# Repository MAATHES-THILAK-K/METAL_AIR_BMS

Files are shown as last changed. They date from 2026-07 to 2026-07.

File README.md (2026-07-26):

# 🔋 Metal-Air Single Cell Battery Management System 




<p align="center">
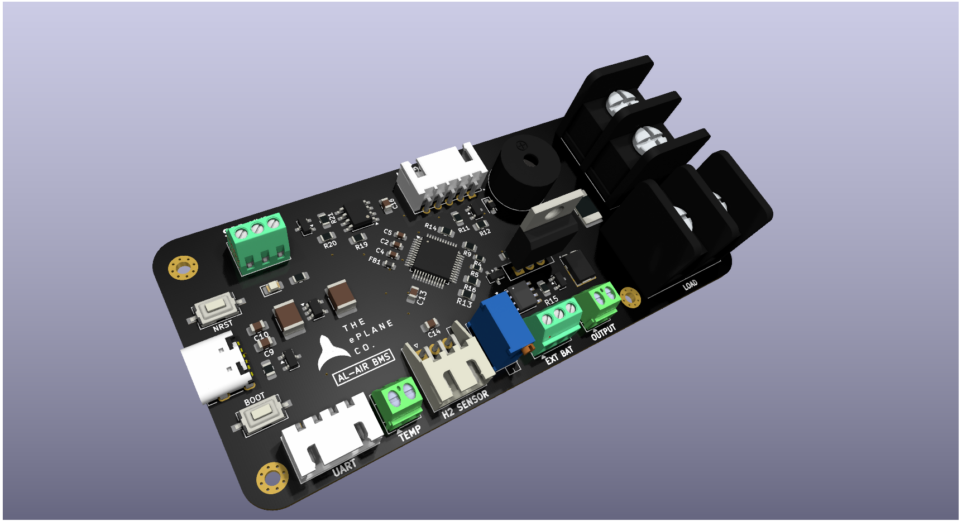
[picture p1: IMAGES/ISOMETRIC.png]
PCB Render
  
</p>

---

## 📖 Overview

The **Metal-Air Single Cell Battery Management System (BMS)** is a custom embedded system designed to safely monitor and protect a single-cell Metal-Air battery. The project is built around the **STM32G0B1CBT6** microcontroller and provides real-time monitoring of battery voltage, current, temperature, and hydrogen gas concentration while implementing multiple protection mechanisms to ensure reliable battery operation.

The repository contains the complete embedded firmware, hardware design files, Python monitoring application, and supporting documentation required to reproduce the project.

---

## ✨ Key Features

* STM32G0B1CBT6 Microcontroller
* INA226 High-Precision Current & Bus Voltage Monitoring
* NTC Thermistor-Based Temperature Measurement
* Hydrogen Gas Sensor Monitoring
* Real-Time Fault Detection
* Over-Current Protection (OCP)
* Under-Voltage Protection (UVP)
* Over-Temperature Protection (OTP)
* UART Communication
* Python-Based Monitoring & Data Logging
* Audible Fault Indication (Buzzer)
* MOSFET-Based Load Disconnect

---

## 🏗️ System Architecture

```text
                  +----------------------------+
                  |    Metal-Air Battery       |
                  +-------------+--------------+
                                |
                 +--------------v--------------+
                 |       STM32G0B1CBT6         |
                 +--------------+--------------+
                                |
     +------------+-------------+------------+--------------+
     |            |                          |              |
     |            |                          |              |
+----v----+ +-----v-----+            +-------v------+ +-----v------+
| INA226  | | NTC Sensor|            | H₂ Sensor    | | UART Debug |
| Current | |Temperature|            | Monitoring   | | / Logging  |
+---------+ +-----------+            +--------------+ +------------+
       |                                           |
       +----------------------+--------------------+
                              |
                      +-------v--------+
                      | Protection     |
                      | Decision Logic |
                      +-------+--------+
                              |
                   +----------v-----------+
                   | MOSFET Load Control  |
                   +----------------------+
```

---

## 🔧 Hardware

### Microcontroller

* STM32G0B1CBT6

### Sensors

* INA226 Current & Bus Voltage Sensor
* NTC Thermistor
* Hydrogen Gas Sensor

### Output Devices

* Protection MOSFET
* Buzzer

### Communication

* UART Serial Interface

---

## 💻 Firmware

The embedded firmware continuously performs the following tasks:

* Battery Voltage Measurement
* Current Measurement
* Temperature Monitoring
* Hydrogen Gas Detection
* Fault Monitoring
* Protection Decision Making
* MOSFET Control
* UART Data Transmission for Monitoring

---

## 📂 Project Structure

```text
Metal-Air-Single-Cell-BMS/
│
├── Firmware/
│   └── Metal_Air_BMS.ino
│
├── Python/
│   └── BMS_Monitor.py
│
├── Hardware/
│   ├── Schematic.pdf
│   ├── PCB.pdf
│   ├── PCB_Render.png
│   ├── PCB_Top.png
│   ├── PCB_Bottom.png
│   ├── Gerber.zip
│   ├── BOM.xlsx
│   └── Pick_and_Place.csv
│
├── Images/
│   ├── PCB_Render.png
│   ├── Completed_PCB.jpg
│   ├── Wiring_Diagram.png
│   └── Block_Diagram.png
│
├── README.md
├── requirements.txt
└── .gitignore
```

---

## 🚀 Getting Started

### Hardware

1. Assemble the PCB.
2. Connect the Metal-Air battery.
3. Connect the sensors.
4. Verify all wiring before powering the system.

### Firmware

Compile the firmware using the **Arduino IDE** with the **STM32 Arduino Core** installed.

Upload the firmware using:

* ST-Link
* UART Bootloader

---

## 🎯 Applications

* Metal-Air Battery Research
* Battery Safety Systems
* Embedded Systems Development
* Laboratory Testing
* Battery Performance Evaluation
* Educational and Research Projects

---

## 👨‍💻 Author

**MAATHES THILAK K**

Electronics and Communication Engineering

Anna University, MIT Campus, Chennai

---
⭐ If you found this project useful, consider giving it a **Star**!

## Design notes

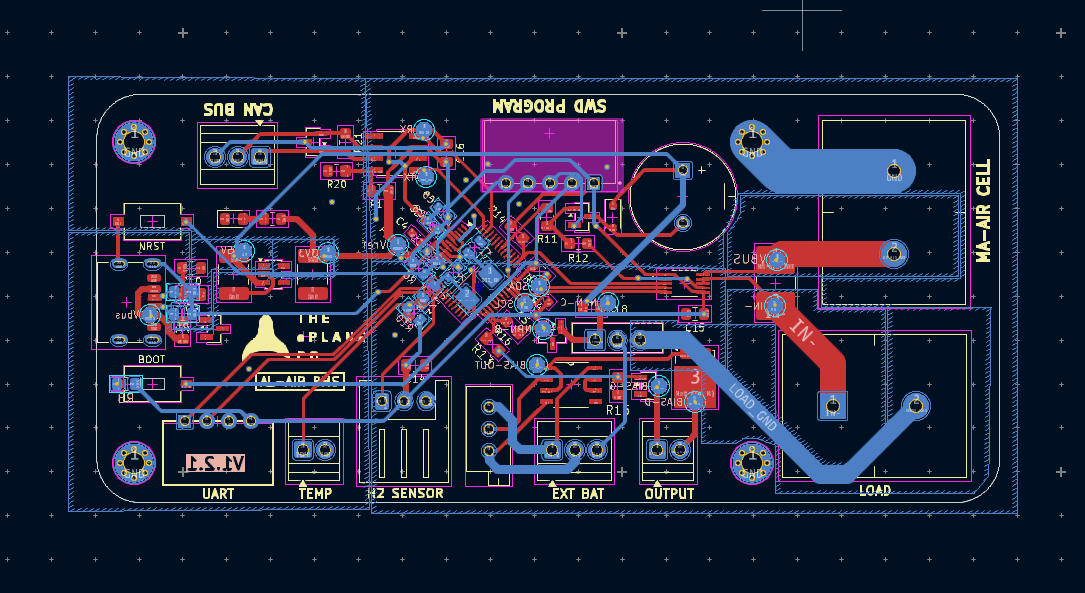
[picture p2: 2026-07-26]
IMAGES/Screenshot from 2026-06-24 11-21-53.png

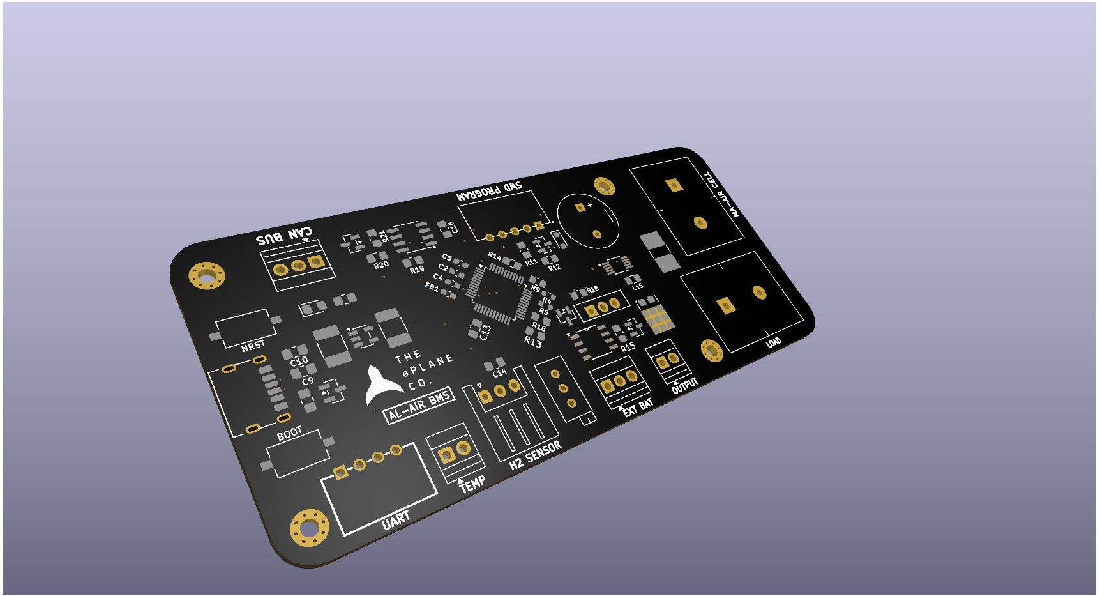
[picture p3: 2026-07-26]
IMAGES/ISOMETRIC_SMD.png

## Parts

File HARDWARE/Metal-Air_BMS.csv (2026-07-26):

Id | Designator | Footprint | Quantity | Designation | Supplier and ref
1 | F1 | Fuse_0805_2012Metric_Pad1.15x1.40mm_HandSolder | 1 | Fuse
2 | R12,R14,R20,R15,R18,R10 | R_0805_2012Metric_Pad1.20x1.40mm_HandSolder | 6 | 10k
3 | U4 | SOIC-8_3.9x4.9mm_P1.27mm | 1 | SN65HVD230
4 | TH1 | TerminalBlock_Xinya_XY308-2.54-2P_1x02_P2.54mm_Horizontal | 1 | 100k ,B=3950
5 | D4 | TO-277A | 1 | ST2045L
6 | C4 | C_0603_1608Metric | 1 | 1uF
7 | R5,R4 | R_0603_1608Metric | 2 | 4k7
8 | R13,R11 | R_0805_2012Metric_Pad1.20x1.40mm_HandSolder | 2 | 100
9 | Q3 | SOT-23 | 1 | BC547
10 | J5,J10 | TerminalBlock_Xinya_XY308-2.54-3P_1x03_P2.54mm_Horizontal | 2 | 01x03
11 | RV1 | Potentiometer_Bourns_3296X_Horizontal | 1 | 10k
12 | J6 | TerminalBlock_Xinya_XY845A-9.50-2P_1x02_P9.50mm | 1 | 01x02
13 | C3,C7 | C_1812_4532Metric_Pad1.57x3.40mm_HandSolder | 2 | 6.8uF
14 | MOSFET1 | TO-220-3_Vertical | 1 | IRLB8743PBF
15 | Q2,Q1 | SOT-23 | 2 | CMN2302M
16 | C2,C5,C1,C6 | C_0603_1608Metric | 4 | 100nF
17 | J1 | USB_C_Receptacle_HRO_TYPE-C-31-M-17 | 1 | USB 3.1 Type-C 6
18 | C9 | C_0805_2012Metric_Pad1.18x1.45mm_HandSolder | 1 | 10uF
19 | J8 | TerminalBlock_Xinya_XY845A-9.50-2P_1x02_P9.50mm | 1 | LOAD
20 | C16,C13,C15,C10,C14 | C_0805_2012Metric_Pad1.18x1.45mm_HandSolder | 5 | 100nF
21 | R3 | R_0805_2012Metric_Pad1.20x1.40mm_HandSolder | 1 | 1k
22 | R21 | R_0805_2012Metric_Pad1.20x1.40mm_HandSolder | 1 | 120
23 | SW1,SW2 | SW_Tactile_SPST_NO_Straight_CK_PTS636Sx25SMTRLFS | 2 | PUSH
24 | FB1 | L_0603_1608Metric | 1 | 220R @ 100MHz
25 | U3 | INA226 | 1 | INA226
26 | D5,D1 | SOT-23 | 2 | TVS_DUAL
27 | J9 | CONN-TH_4P-P2.50_WAFER-XH254WZ-4A | 1 | 01x04
28 | R17 | R_2816_7142Metric_Pad3.20x4.45mm_HandSolder | 1 | 3m
29 | U2 | LQFP-48_7x7mm_P0.5mm | 1 | STM32G0B1CBTx
30 | J7 | TerminalBlock_Xinya_XY308-2.54-2P_1x02_P2.54mm_Horizontal | 1 | 01x02
31 | R19 | R_0805_2012Metric_Pad1.20x1.40mm_HandSolder | 1 | 0
32 | U5 | TS9121IDT | 1 | TS912IDT
33 | D2 | LED_0805_2012Metric_Pad1.15x1.40mm_HandSolder | 1 | LED
34 | J4 | JST_XH_S3B-XH-A_1x03_P2.50mm_Horizontal | 1 | 01x03
35 | R9,R6 | R_0805_2012Metric | 2 | 10k
36 | U1 | SOT-23-5 | 1 | SSP7603P33M5R
37 | J3 | Buzzer_12x9.5RM6.0 | 1 | 01x02
38 | R16 | R_0805_2012Metric_Pad1.20x1.40mm_HandSolder | 1 | 4k7
39 | D3 | D_SOD-323_HandSoldering | 1 | RB550V
40 | J2 | JST_GENERIC_5-PIN | 1 | 01x05
41 | TP10 | TestPoint_Pad_D1.5mm | 1 | VBUS
42 | TP5 | TestPoint_Pad_D1.5mm | 1 | Vref
43 | C8 | C_0603_1608Metric | 1 | 4.7uF
44 | TP11 | TestPoint_Pad_D1.5mm | 1 | NPN-B
45 | TP8 | TestPoint_Pad_D1.5mm | 1 | RX
46 | R1,R2 | R_0805_2012Metric_Pad1.20x1.40mm_HandSolder | 2 | 5.1k
47 | R7 | R_0603_1608Metric | 1 | 620
48 | TP6 | TestPoint_Pad_D1.5mm | 1 | SCL
49 | TP4 | TestPoint_Pad_D1.5mm | 1 | SDA
50 | TP2 | TestPoint_Pad_D1.5mm | 1 | Vbus
51 | C12,C11 | C_0805_2012Metric | 2 | 30pF
52 | TP9 | TestPoint_Pad_D1.5mm | 1 | IN-
53 | Y1 | Crystal_SMD_5032-2Pin_5.0x3.2mm | 1 | 8MHz
54 | TP7 | TestPoint_Pad_D1.5mm | 1 | TX
55 | TP1 | TestPoint_Pad_D1.5mm | 1 | 5V
56 | R8 | R_0805_2012Metric_Pad1.20x1.40mm_HandSolder | 1 | 330
57 | TP16 | TestPoint_Pad_D1.5mm | 1 | BIAS-OUT
58 | TP13 | TestPoint_Pad_D1.5mm | 1 | NPN-C
59 | TP3 | TestPoint_Pad_D1.5mm | 1 | 3V3
60 | TP14 | TestPoint_Pad_D1.5mm | 1 | BIAS-D
61 | TP12 | TestPoint_Pad_D1.5mm | 1 | BIAS-G

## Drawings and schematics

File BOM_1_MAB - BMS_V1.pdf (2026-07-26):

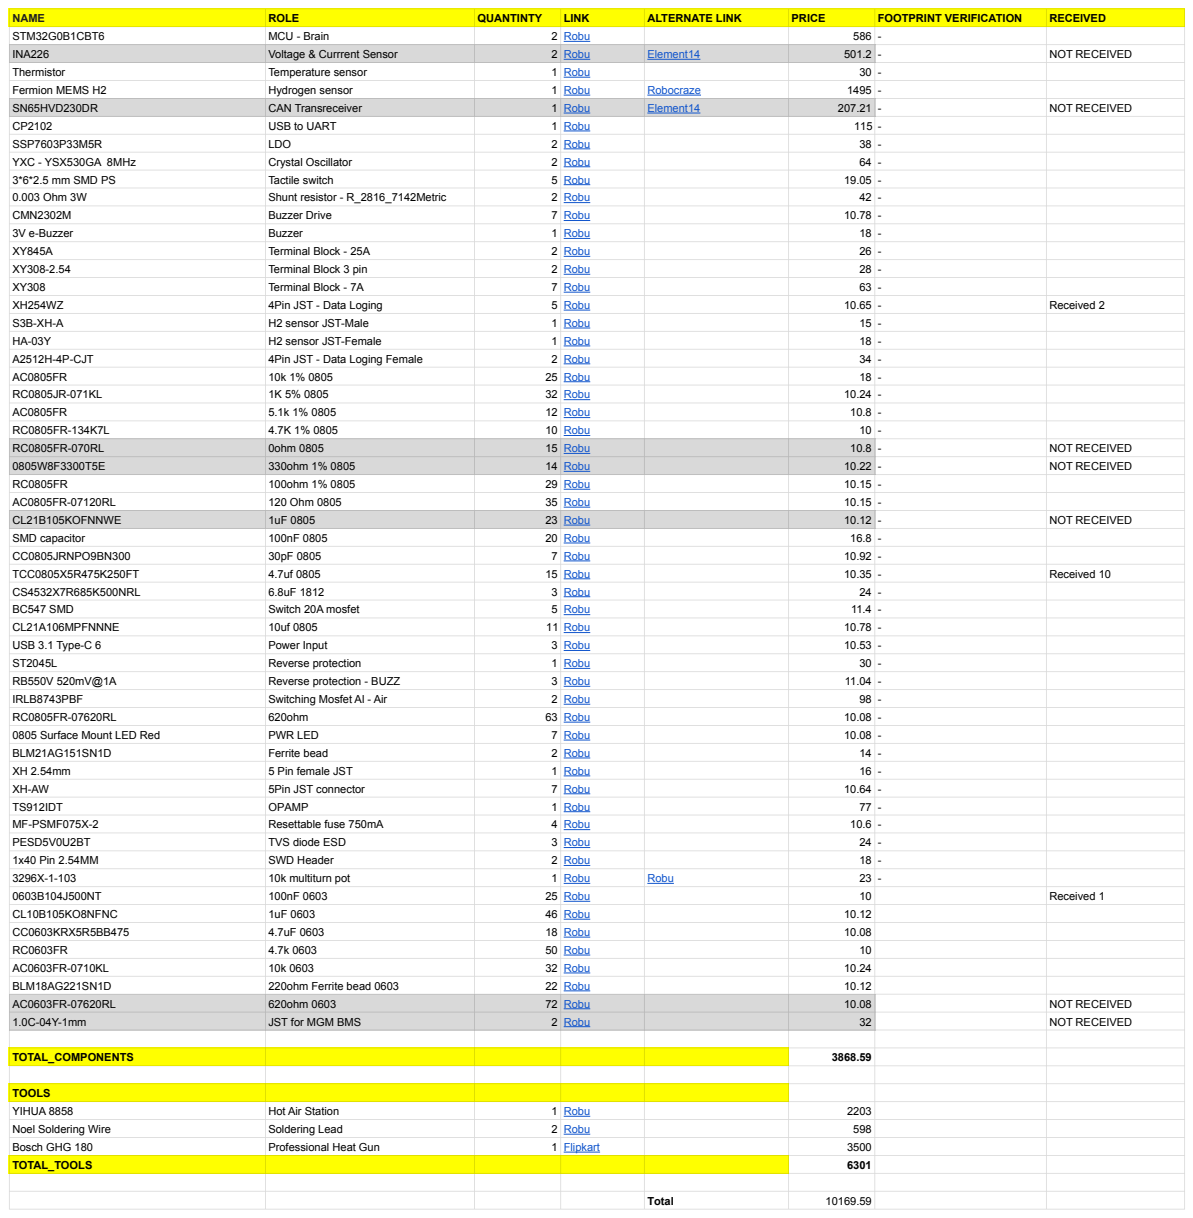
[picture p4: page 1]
NAME; ROLE; QUANTINTY; LINK; ALTERNATE LINK; PRICE; FOOTPRINT VERIFICATION; RECEIVED; STM32G0B1CBT6; MCU - Brain; 2 Robu; INA226; Voltage & Currrent Sensor; Element14; NOT RECEIVED; Thermistor; Temperature sensor; 1 Robu; Fermion MEMS H2; Hydrogen sensor; Robocraze; SN65HVD230DR; CAN Transreceiver; USB to UART; SSP7603P33M5R; LDO; YXC - YSX530GA 8MHz; Crystal Oscillator; 3*6*2.5 mm SMD PS; Tactile switch; 5 Robu; 0.003 Ohm 3W; Shunt resistor - R_2816_7142Metric; CMN2302M; Buzzer Drive; 7 Robu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

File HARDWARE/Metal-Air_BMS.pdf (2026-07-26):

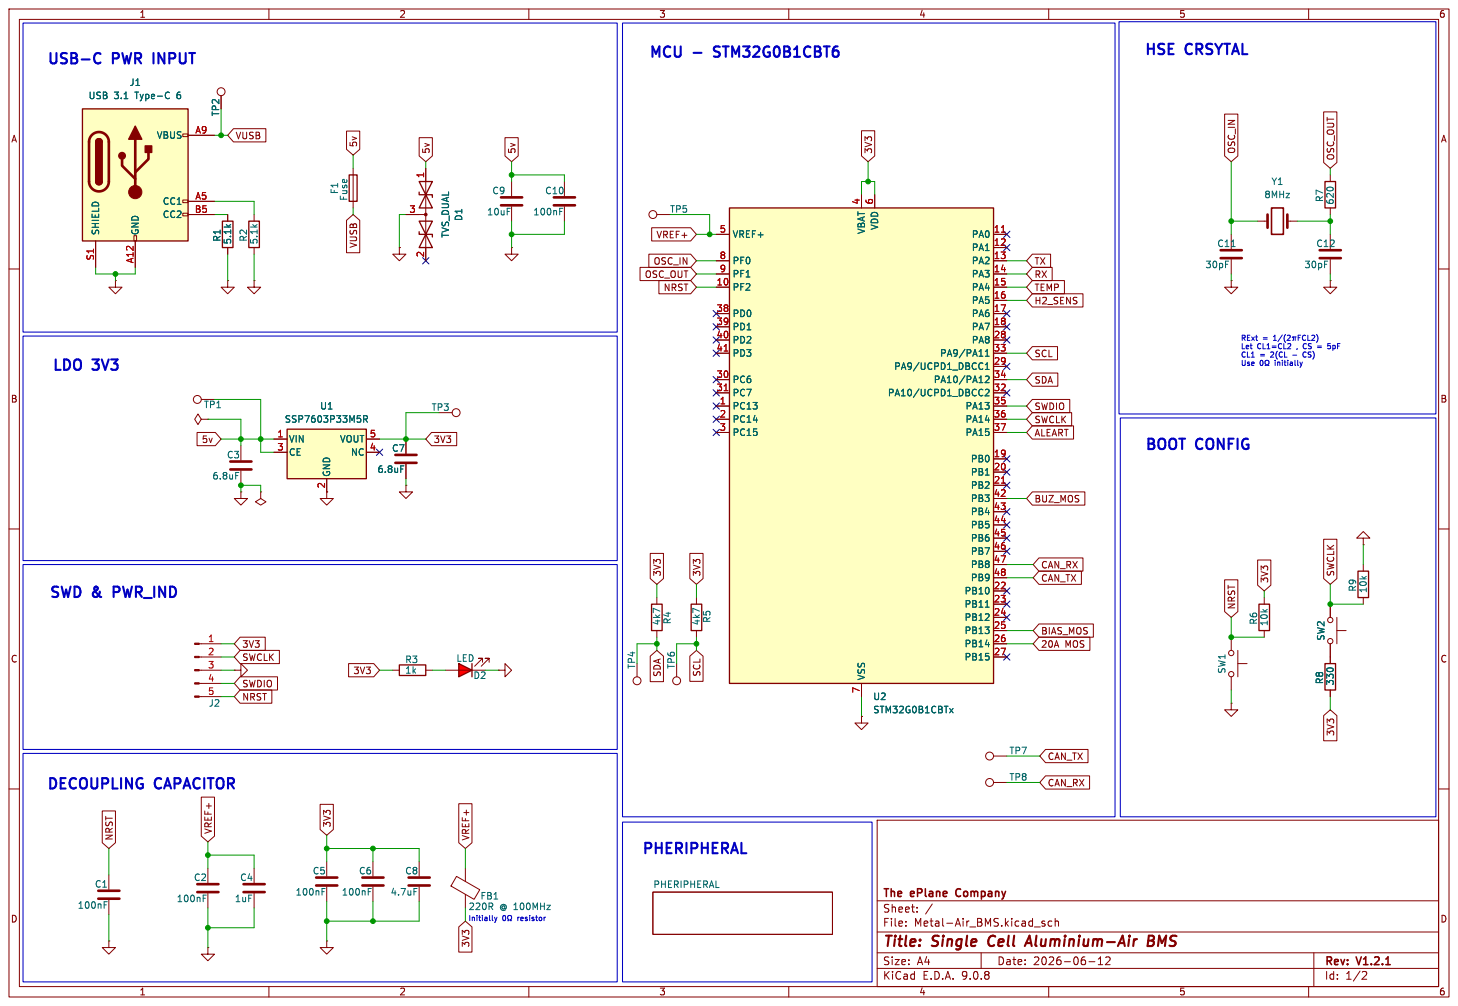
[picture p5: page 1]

File: Metal-Air_BMS.kicad_sch Sheet: / The ePlane Company PHERIPHERAL

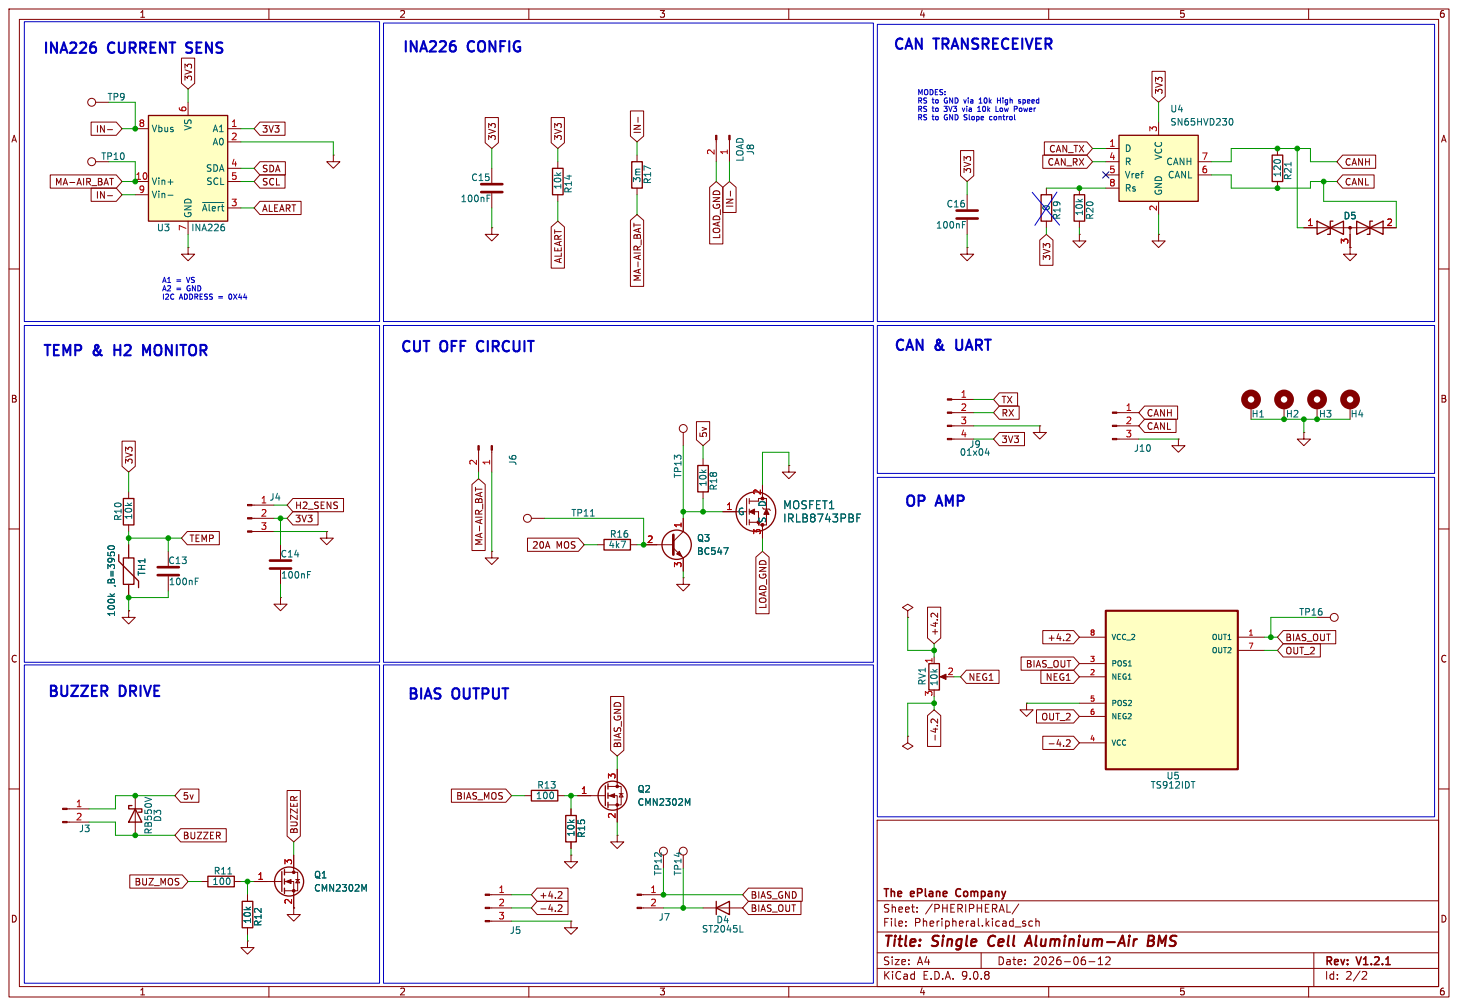
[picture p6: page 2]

MODES: RS to GND via 10k High speed RS to 3V3 via 10k Low Power RS to GND Slope control CAN TRANSRECEIVER

File: Pheripheral.kicad_sch Sheet: /PHERIPHERAL/ The ePlane Company TP13 TP11

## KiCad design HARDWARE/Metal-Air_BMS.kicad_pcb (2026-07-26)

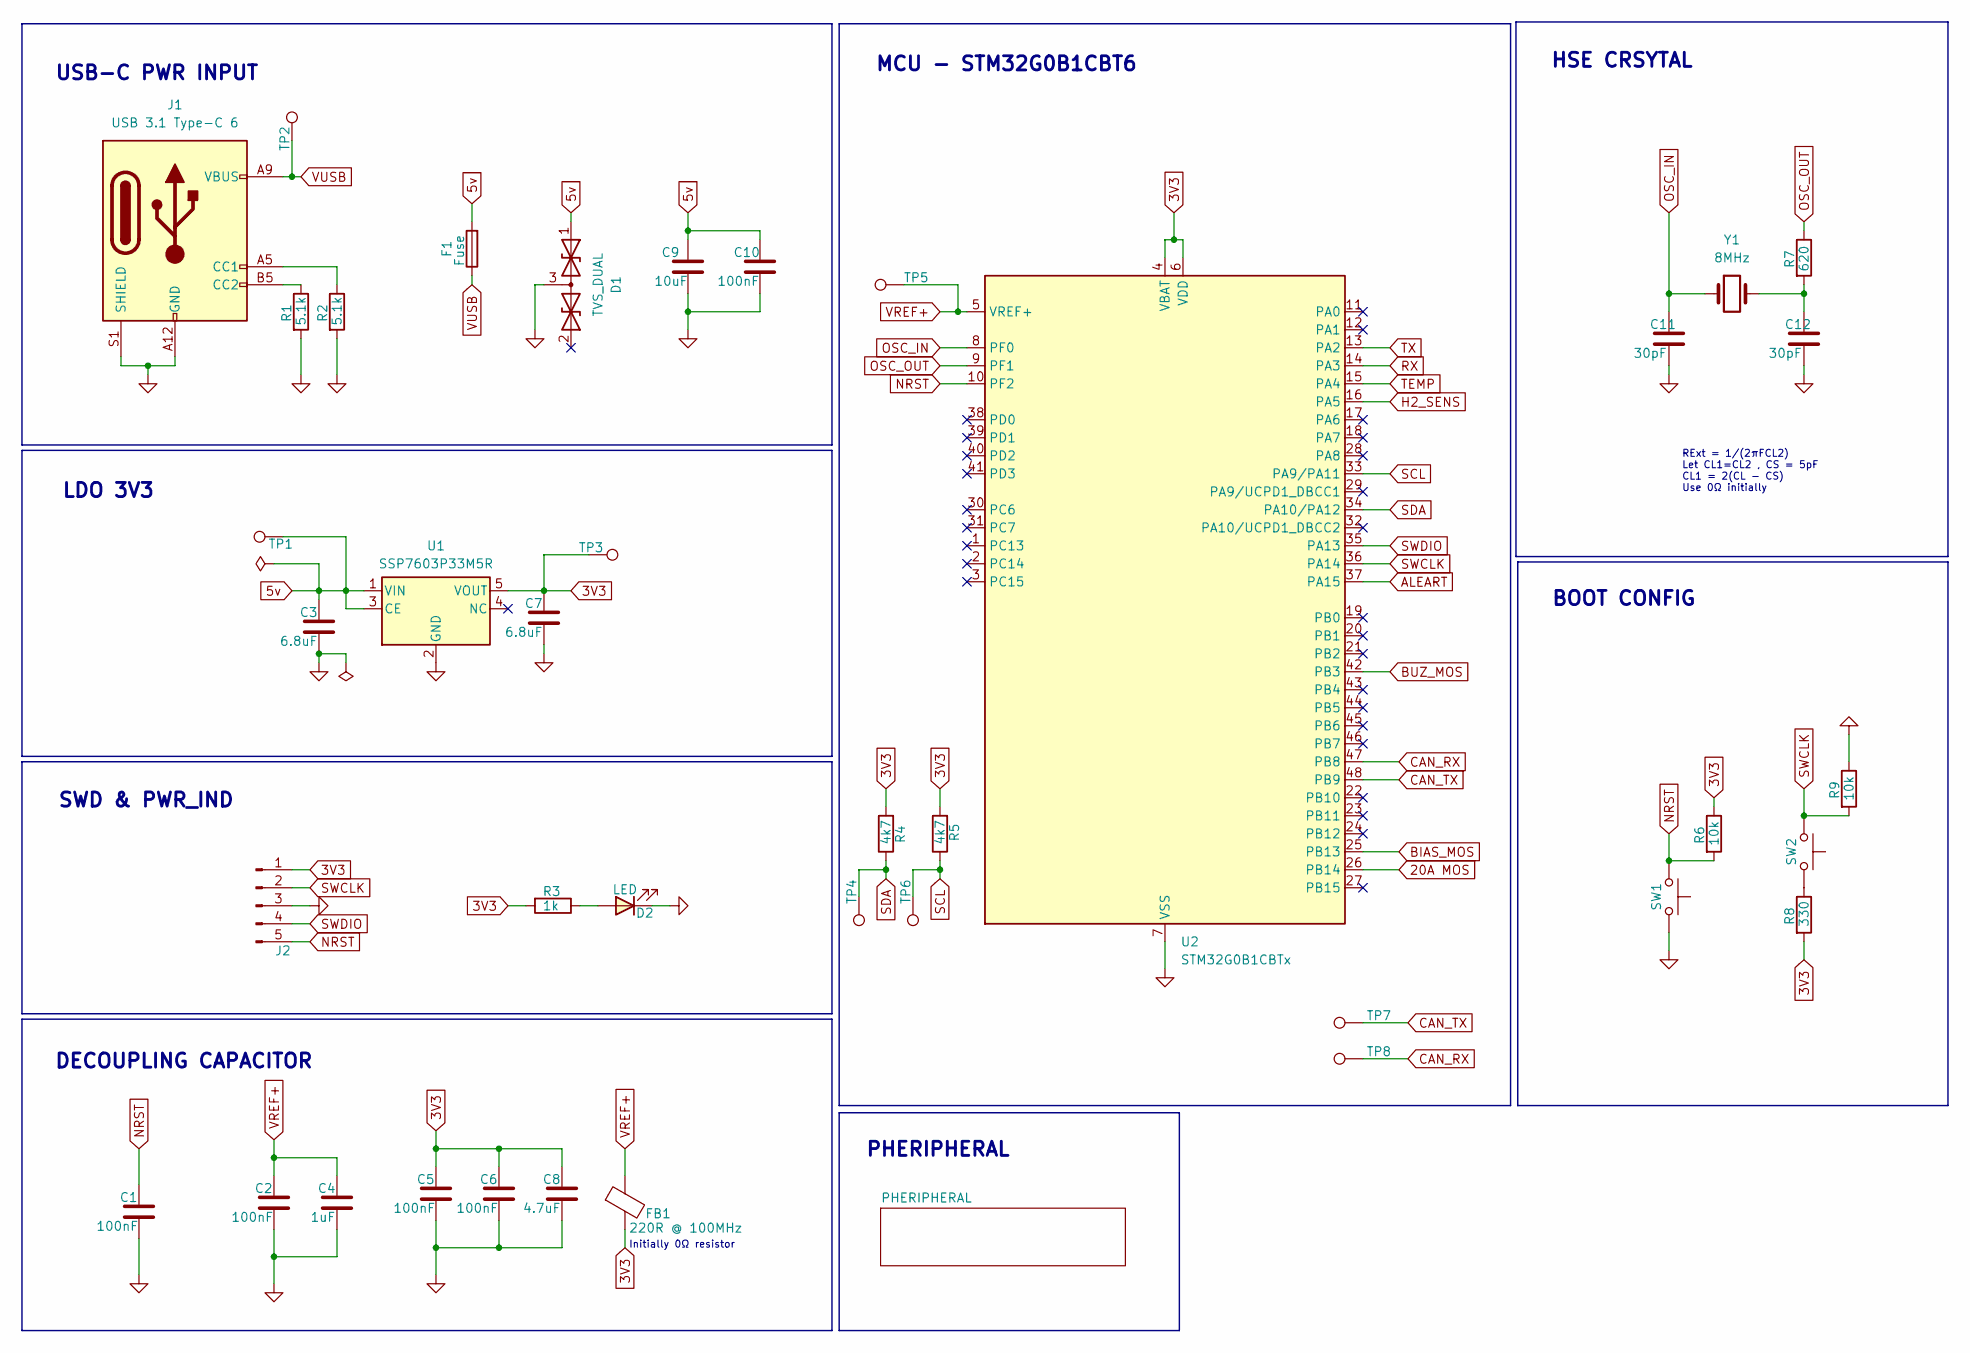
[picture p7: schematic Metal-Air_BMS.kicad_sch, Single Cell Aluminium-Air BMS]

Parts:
C1, C2, C5, C6: 100nF; C_0603_1608Metric
C3, C7: 6.8uF; C_1812_4532Metric_Pad1.57x3.40mm_HandSolder
C4: 1uF; C_0603_1608Metric
C8: 4.7uF; C_0603_1608Metric
C9: 10uF; C_0805_2012Metric_Pad1.18x1.45mm_HandSolder
C10: 100nF; C_0805_2012Metric_Pad1.18x1.45mm_HandSolder
C11, C12: 30pF; C_0805_2012Metric
D1: TVS_DUAL; SOT-23
D2: LED; LED_0805_2012Metric_Pad1.15x1.40mm_HandSolder
F1: Fuse; Fuse_0805_2012Metric_Pad1.15x1.40mm_HandSolder
FB1: 220R @ 100MHz; L_0603_1608Metric
J1: USB 3.1 Type-C 6; USB_C_Receptacle_HRO_TYPE-C-31-M-17
J2: 01x05; JST_GENERIC_5-PIN
R1, R2: 5.1k; R_0805_2012Metric_Pad1.20x1.40mm_HandSolder
R3: 1k; R_0805_2012Metric_Pad1.20x1.40mm_HandSolder
R4, R5: 4k7; R_0603_1608Metric
R6, R9: 10k; R_0805_2012Metric
R7: 620; R_0603_1608Metric
R8: 330; R_0805_2012Metric_Pad1.20x1.40mm_HandSolder
SW1, SW2: PUSH; SW_Tactile_SPST_NO_Straight_CK_PTS636Sx25SMTRLFS
TP1: 5V; TestPoint_Pad_D1.5mm
TP2: Vbus; TestPoint_Pad_D1.5mm
TP3: 3V3; TestPoint_Pad_D1.5mm
TP4: SDA; TestPoint_Pad_D1.5mm
TP5: Vref; TestPoint_Pad_D1.5mm
TP6: SCL; TestPoint_Pad_D1.5mm
TP7: TX; TestPoint_Pad_D1.5mm
TP8: RX; TestPoint_Pad_D1.5mm
U1: SSP7603P33M5R; SOT-23-5
U2: STM32G0B1CBTx; LQFP-48_7x7mm_P0.5mm
Y1: 8MHz; Crystal_SMD_5032-2Pin_5.0x3.2mm

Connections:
3V3: C5.1, C6.1, C7.1, C8.1, FB1.2, J2.1, R3.2, R4.2, R5.2, R6.1, R8.2, TP3.1, U1.5 (VOUT), U2.4 (VBAT), U2.6 (VDD); also elsewhere on the board
5v: C3.1, C9.1, C10.1, D1.1 (A1), F1.2, TP1.1, U1.1 (VIN), U1.3 (CE); also elsewhere on the board
20A MOS: U2.26 (PB14); also elsewhere on the board
ALEART: U2.37 (PA15); also elsewhere on the board
BIAS_MOS: U2.25 (PB13); also elsewhere on the board
BUZ_MOS: U2.42 (PB3); also elsewhere on the board
CAN_RX: TP8.1, U2.47 (PB8); also elsewhere on the board
CAN_TX: TP7.1, U2.48 (PB9); also elsewhere on the board
GND: C1.2, C2.2, C3.2, C4.2, C5.2, C6.2, C7.2, C8.2, C9.2, C10.2, C11.2, C12.2, D1.3 (common), D2.1 (K), J1.A12 (GND), J1.B12 (GND), J1.S1 (SHIELD), J2.3, R1.2, R2.2, R9.1, SW1.2, U1.2 (GND), U2.7 (VSS); also elsewhere on the board
H2_SENS: U2.16 (PA5); also elsewhere on the board
NRST: C1.1, J2.5, R6.2, SW1.1, U2.10 (PF2)
unnamed: C12.1, R7.2, Y1.2
unnamed: D2.2 (A), R3.1
unnamed: J1.A5 (CC1), R2.1
unnamed: J1.B5 (CC2), R1.1
unnamed: R8.1, SW2.2
OSC_IN: C11.1, U2.8 (PF0), Y1.1
OSC_OUT: R7.1, U2.9 (PF1)
RX: U2.14 (PA3); also elsewhere on the board
SCL: R5.1, TP6.1, U2.33 (PA9/PA11); also elsewhere on the board
SDA: R4.1, TP4.1, U2.34 (PA10/PA12); also elsewhere on the board
SWCLK: J2.2, R9.2, SW2.1, U2.36 (PA14)
SWDIO: J2.4, U2.35 (PA13)
TEMP: U2.15 (PA4); also elsewhere on the board
TX: U2.13 (PA2); also elsewhere on the board
VREF+: C2.1, C4.1, FB1.1, TP5.1, U2.5 (VREF+)
VUSB: F1.1, J1.A9 (VBUS), J1.B9 (VBUS), TP2.1

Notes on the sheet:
LDO 3V3
DECOUPLING CAPACITOR
RExt = 1/(2πFCL2) Let CL1=CL2 , CS = 5pF CL1 = 2(CL - CS) Use 0Ω initially
MCU - STM32G0B1CBT6
Initially 0Ω resistor
USB-C PWR INPUT
SWD & PWR_IND
HSE CRSYTAL
PHERIPHERAL
BOOT CONFIG

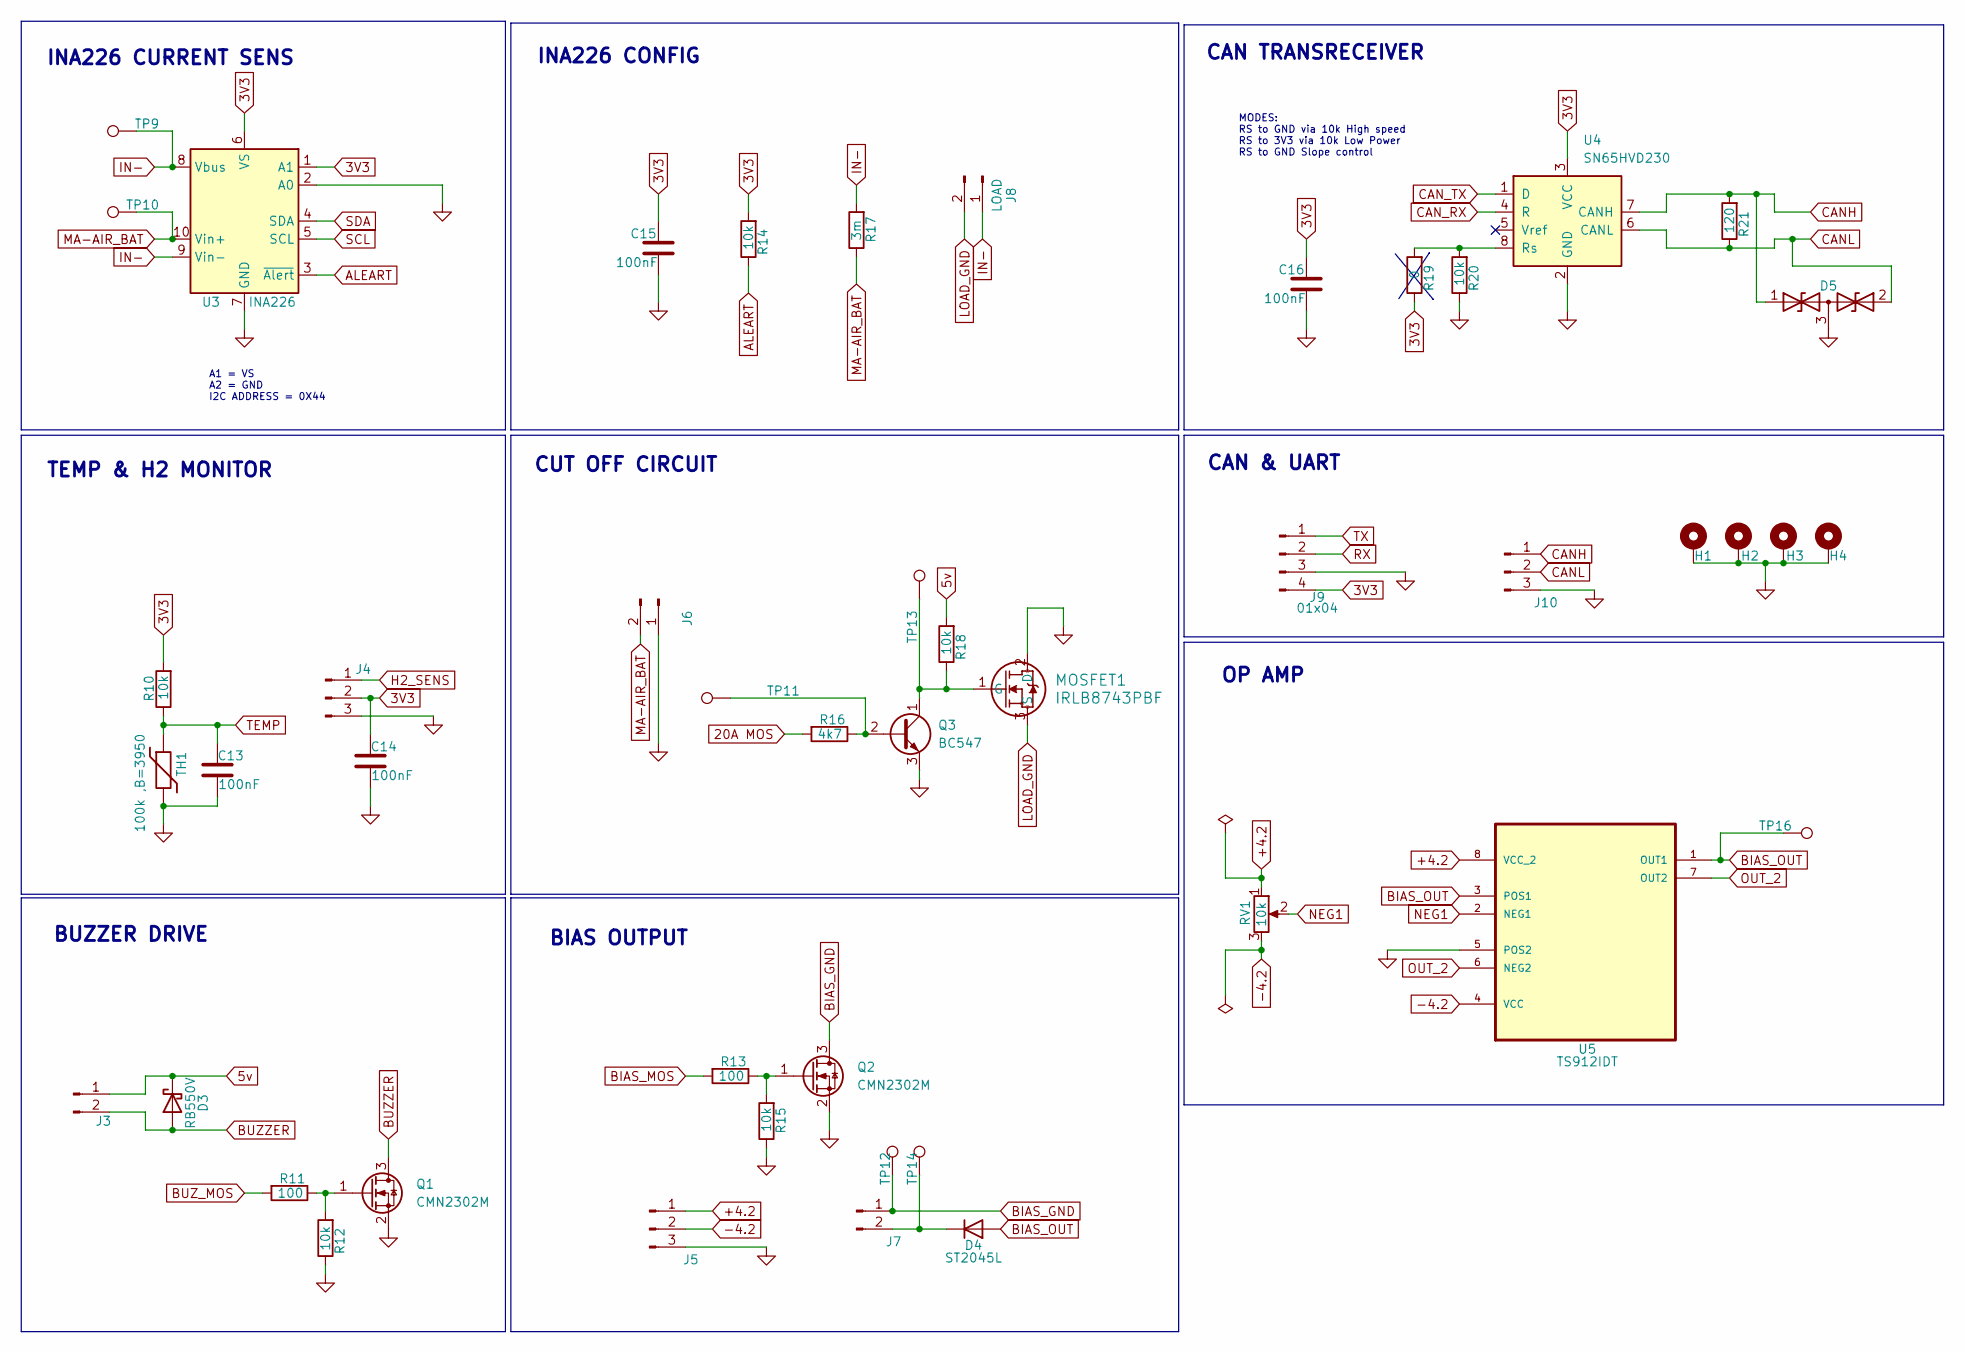
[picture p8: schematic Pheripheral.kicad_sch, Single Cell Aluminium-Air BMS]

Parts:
C13, C14, C15, C16: 100nF; C_0805_2012Metric_Pad1.18x1.45mm_HandSolder
D3: RB550V; D_SOD-323_HandSoldering
D4: ST2045L; TO-277A
D5: TVS_DUAL; SOT-23
H1, H2, H3, H4: MountingHole_Pad; MountingHole_2.2mm_M2_Pad_Via
J3: 01x02; Buzzer_12x9.5RM6.0
J4: 01x03; JST_XH_S3B-XH-A_1x03_P2.50mm_Horizontal
J5, J10: 01x03; TerminalBlock_Xinya_XY308-2.54-3P_1x03_P2.54mm_Horizontal
J6: 01x02; TerminalBlock_Xinya_XY845A-9.50-2P_1x02_P9.50mm
J7: 01x02; TerminalBlock_Xinya_XY308-2.54-2P_1x02_P2.54mm_Horizontal
J8: LOAD; TerminalBlock_Xinya_XY845A-9.50-2P_1x02_P9.50mm
J9: 01x04; CONN-TH_4P-P2.50_WAFER-XH254WZ-4A
MOSFET1: IRLB8743PBF; TO-220-3_Vertical
Q1, Q2: CMN2302M; SOT-23
Q3: BC547; SOT-23
R10, R12, R14, R15, R18, R20: 10k; R_0805_2012Metric_Pad1.20x1.40mm_HandSolder
R11, R13: 100; R_0805_2012Metric_Pad1.20x1.40mm_HandSolder
R16: 4k7; R_0805_2012Metric_Pad1.20x1.40mm_HandSolder
R17: 3m; R_2816_7142Metric_Pad3.20x4.45mm_HandSolder
R19: 0; R_0805_2012Metric_Pad1.20x1.40mm_HandSolder
R21: 120; R_0805_2012Metric_Pad1.20x1.40mm_HandSolder
RV1: 10k; Potentiometer_Bourns_3296X_Horizontal
TH1: 100k ,B=3950; TerminalBlock_Xinya_XY308-2.54-2P_1x02_P2.54mm_Horizontal
TP9: IN-; TestPoint_Pad_D1.5mm
TP10: VBUS; TestPoint_Pad_D1.5mm
TP11: NPN-B; TestPoint_Pad_D1.5mm
TP12: BIAS-G; TestPoint_Pad_D1.5mm
TP13: NPN-C; TestPoint_Pad_D1.5mm
TP14: BIAS-D; TestPoint_Pad_D1.5mm
TP16: BIAS-OUT; TestPoint_Pad_D1.5mm
U3: INA226
U4: SN65HVD230; SOIC-8_3.9x4.9mm_P1.27mm
U5: TS912IDT; TS9121IDT; MPN TS912ID

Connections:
3V3: C14.1, C15.1, C16.1, J4.2, J9.4, R10.2, R14.2, R19.1, U3.1 (A1), U3.6 (VS), U4.3 (VCC); also elsewhere on the board
5v: D3.1 (K), J3.1, R18.2; also elsewhere on the board
20A MOS: R16.2; also elsewhere on the board
+4.2: J5.1, RV1.1, U5.8 (VCC_2)
-4.2: J5.2, RV1.3, U5.4 (VCC)
ALEART: R14.1, U3.3 (~Alert); also elsewhere on the board
BIAS_GND: J7.1, Q2.3 (D), TP12.1
BIAS_MOS: R13.2; also elsewhere on the board
BIAS_OUT: D4.1 (A), D4.2 (A), TP16.1, U5.1 (OUT1), U5.3 (POS1)
BUZZER: D3.2 (A), J3.2, Q1.3 (D)
BUZ_MOS: R11.2; also elsewhere on the board
CANH: D5.1 (A1), J10.1, R21.2, U4.7 (CANH)
CANL: D5.2 (A2), J10.2, R21.1, U4.6 (CANL)
CAN_RX: U4.4 (R); also elsewhere on the board
CAN_TX: U4.1 (D); also elsewhere on the board
GND: C13.2, C14.2, C15.2, C16.2, D5.3 (common), H1.1, H2.1, H3.1, H4.1, J4.3, J5.3, J6.1, J9.3, J10.3, MOSFET1.2 (D), Q1.2 (S), Q2.2 (S), Q3.3 (E), R12.1, R15.1, R20.1, TH1.2, U3.2 (A0), U3.7 (GND), U4.2 (GND), U5.5 (POS2); also elsewhere on the board
H2_SENS: J4.1; also elsewhere on the board
IN-: J8.1, R17.2, TP9.1, U3.8 (Vbus), U3.9 (Vin-)
LOAD_GND: J8.2, MOSFET1.3 (S)
MA-AIR_BAT: J6.2, R17.1, TP10.1, U3.10 (Vin+)
NEG1: RV1.2, U5.2 (NEG1)
unnamed: D4.3 (K), J7.2, TP14.1
unnamed: MOSFET1.1 (G), Q3.1 (C), R18.1, TP13.1
unnamed: Q1.1 (G), R11.1, R12.2
unnamed: Q2.1 (G), R13.1, R15.2
unnamed: Q3.2 (B), R16.1, TP11.1
unnamed: R19.2, R20.2, U4.8 (Rs)
OUT_2: U5.6 (NEG2), U5.7 (OUT2)
RX: J9.2; also elsewhere on the board
SCL: U3.5 (SCL); also elsewhere on the board
SDA: U3.4 (SDA); also elsewhere on the board
TEMP: C13.1, R10.1, TH1.1; also elsewhere on the board
TX: J9.1; also elsewhere on the board

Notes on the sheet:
BIAS OUTPUT
BUZZER DRIVE
OP AMP
CAN & UART
CAN TRANSRECEIVER
TEMP & H2 MONITOR
INA226 CURRENT SENS
CUT OFF CIRCUIT
INA226 CONFIG
A1 = VS A2 = GND I2C ADDRESS = 0X44
MODES: RS to GND via 10k High speed RS to 3V3 via 10k Low Power RS to GND Slope control

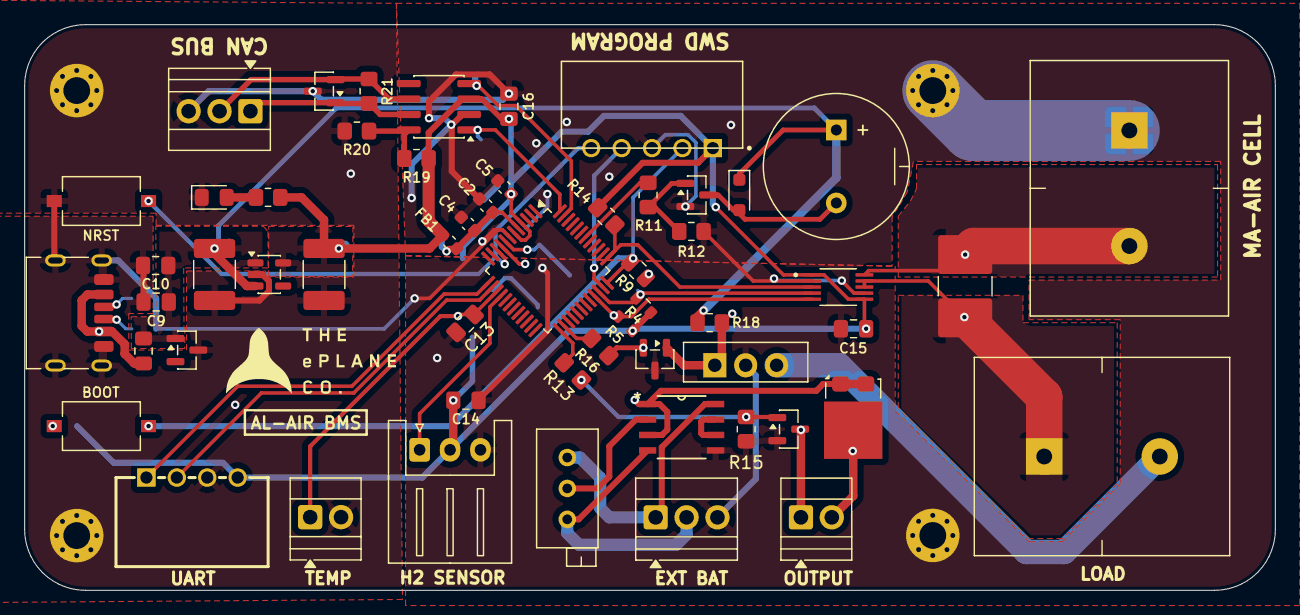
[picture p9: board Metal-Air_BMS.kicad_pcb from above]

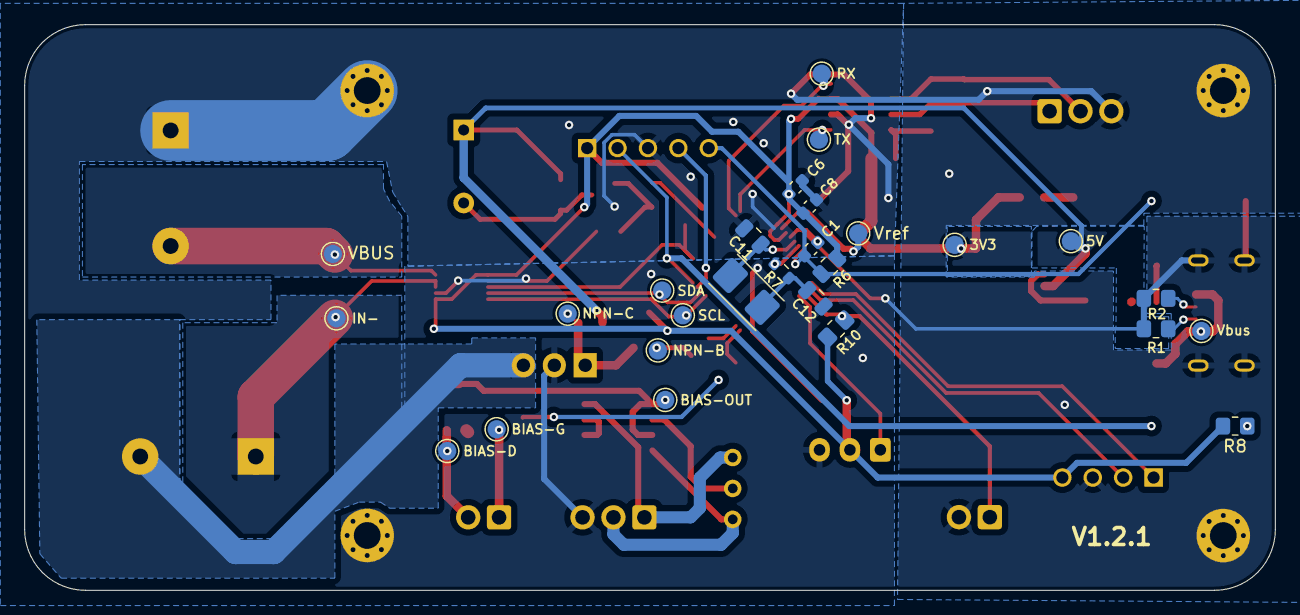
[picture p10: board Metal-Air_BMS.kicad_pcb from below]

Board: 2 copper layers, 102.8 x 46.5 mm, 87 parts (27 on the bottom side), 45 nets.

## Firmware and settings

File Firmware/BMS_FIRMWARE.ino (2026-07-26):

#include <Arduino.h>
#include <Wire.h>
#include <math.h>

// ---- pins ----
#define SDA_PIN PA12
#define SCL_PIN PA11
#define ALERT_PIN PA15
#define BUZZER_PIN PB3
#define MOSFET_PIN PB14
#define TEMP_PIN PA4
#define H2_PIN PA5

HardwareSerial Serial1(PA3, PA2);

// ---- INA226 registers ----
#define INA226_ADDR 0x44
#define REG_CONFIG 0x00
#define REG_SHUNT 0x01
#define REG_BUS 0x02
#define REG_POWER 0x03
#define REG_CURRENT 0x04
#define REG_CAL 0x05
#define REG_MASK 0x06
#define REG_ALERT 0x07

// ==================== EDIT THESE TO RECONFIGURE ====================
const float SHUNT_OHMS = 0.003f;     // your shunt
float BUS_VOLTAGE_LIMIT = 0.8f;      // runtime-configurable (SET_V)
const float MAX_CURRENT_A = 20.0f;   // calibration full-scale
float OCP_LIMIT_A = 16.0f;           // cutoff current, runtime-configurable (SET_IH)
float CURRENT_LOWER_LIMIT_A = 0.0f;  // runtime-configurable (SET_IL), 0 = disabled
float TEMP_HIGH_LIMIT = 45.0f;       // deg C, runtime-configurable (SET_TH)
float TEMP_LOW_LIMIT = 25.0f;        // deg C, runtime-configurable (SET_TL)
float H2_LIMIT_V = 4.00f;            // runtime-configurable (SET_H2)
const float NTC_BETA = 3950.0f;
const float NTC_R_FIXED = 100000.0f;      // divider resistor
const float NTC_R0 = 100000.0f;           // NTC resistance @ 25C
const float NTC_T0 = 298.15f;             // 25C in Kelvin
float TEMP_OFFSET = 0.0f;                 // calibrate against a reference thermometer
uint32_t CSV_PERIOD_MS = 1000;            // csv print rate, runtime-configurable (SET_RATE)
const uint32_t BUZZ_PERIOD_MS = 500;      // buz-silent-buz cadence
const bool ENABLE_UART_TELEMETRY = true;  // Set to true to enable, false to disable
const uint32_t CONFIG_WINDOW_MS = 60000;  // window (from boot) during which SET_* commands are accepted
// =====================================================================

const float CURRENT_LSB = MAX_CURRENT_A / 32768.0f;
const float POWER_LSB = 25.0f * CURRENT_LSB;
const uint16_t CAL_REG = (uint16_t)(0.00512f / (CURRENT_LSB * SHUNT_OHMS));

bool faultLatched = false;
bool mosfetOn = false;
bool buzzState = false;
uint32_t lastBuzz = 0;
uint32_t lastCsv = 0;
bool inConfigMode = false;
uint32_t bootTime = 0;

uint8_t faultReason = 0;
String rxLineBuffer = "";

uint16_t computeAlertReg() {
  return (uint16_t)((OCP_LIMIT_A * SHUNT_OHMS) / 0.0000025f);
}

// Fault codes (must match FAULT_MESSAGES in the PC logger exactly):
// 0 = No fault
// 1 = INA226 ALERT pin
// 2 = Bus voltage
// 3 = Over current
// 4 = Hydrogen
// 5 = Temperature
// 6 = Under current

void ina226Write(uint8_t reg, uint16_t val) {
  Wire.beginTransmission(INA226_ADDR);
  Wire.write(reg);
  Wire.write((uint8_t)(val >> 8));
  Wire.write((uint8_t)(val & 0xFF));
  Wire.endTransmission();
}

int16_t ina226Read(uint8_t reg) {
  Wire.beginTransmission(INA226_ADDR);
  Wire.write(reg);
  Wire.endTransmission(false);
  Wire.requestFrom(INA226_ADDR, (uint8_t)2);
  uint16_t val = ((uint16_t)Wire.read() << 8) | Wire.read();
  return (int16_t)val;
}

void ina226Init() {
  Wire.setSDA(SDA_PIN);
  Wire.setSCL(SCL_PIN);
  Wire.begin();
  ina226Write(REG_CONFIG, 0x4127);  // default conv times, continuous mode
  ina226Write(REG_CAL, CAL_REG);
  ina226Write(REG_ALERT, computeAlertReg());  // shunt-over-limit threshold
  ina226Write(REG_MASK, 0x8001);              // enable SOL alert + latch
}

float readBusVoltage() {
  const float BUS_DEADBAND = 0.300f;  // Ignore anything below 300 mV

  float voltage = ina226Read(REG_BUS) * 0.00125f;

  if (voltage < BUS_DEADBAND)
    voltage = 0.0f;

  return voltage;
}
float readCurrent() {
  const uint8_t FILTER_SIZE = 16;
  const float CURRENT_DEADBAND = 0.003f;

  static float buffer[FILTER_SIZE];
  static uint8_t index = 0;
  static bool filled = false;

  float current = ina226Read(REG_CURRENT) * CURRENT_LSB;

  buffer[index] = current;

  index++;

  if (index >= FILTER_SIZE) {
    index = 0;
    filled = true;
  }

  uint8_t count = filled ? FILTER_SIZE : index;

  float sum = 0;

  for (uint8_t i = 0; i < count; i++)
    sum += buffer[i];

  current = sum / count;

  if (fabs(current) < CURRENT_DEADBAND)
    current = 0.0f;

  return current;
}
float readPower() {
  return ina226Read(REG_POWER) * POWER_LSB;
}
float readShuntMv() {
  return ina226Read(REG_SHUNT) * 0.0025f;
}

float readTemperature() {
  const uint16_t samples = 128;
  uint32_t adcSum = 0;
  for (uint16_t i = 0; i < samples; i++) {
    adcSum += analogRead(TEMP_PIN);
    delayMicroseconds(200);
  }

  float adc = (float)adcSum / samples;
  if (adc <= 1) adc = 1;
  if (adc >= 4094) adc = 4094;

  float resistance = NTC_R_FIXED * (adc / (4095.0f - adc));
  float tempK = 1.0f / ((1.0f / NTC_T0) + (1.0f / NTC_BETA) * log(resistance / NTC_R0));

  return (tempK - 273.15f) + TEMP_OFFSET;
}

float readH2() {
  uint32_t sum = 0;
  for (int i = 0; i < 16; i++) {
    sum += analogRead(H2_PIN);
    delayMicroseconds(100);
  }
  float adc = sum / 16.0f;
  return adc * 3.3f / 4095.0f;
}

void checkFaults(float busV, float current, float temp, float h2v) {
  bool configWindowOpen = (millis() - bootTime <= CONFIG_WINDOW_MS);

  if (configWindowOpen) {
    // Re-arm the INA226's internal alert latch every cycle so a raised or
    // lowered OCP limit takes effect immediately instead of staying tripped
    // from an earlier (now-stale) threshold. Reading MASK/ENABLE clears the
    // chip's alert flag; it re-asserts on the very next conversion if the
    // condition is still genuinely violated.
    ina226Read(REG_MASK);
  }

  bool alertActive = (digitalRead(ALERT_PIN) == LOW);

  // Default = no fault
  faultReason = 0;

  // Priority order
  if (alertActive) {
    faultReason = 1;
  } else if (busV < BUS_VOLTAGE_LIMIT) {
    faultReason = 2;
  } else if (current > OCP_LIMIT_A) {
    faultReason = 3;
  } else if (CURRENT_LOWER_LIMIT_A > 0.0f && current < CURRENT_LOWER_LIMIT_A) {
    faultReason = 6;
  } else if (h2v > H2_LIMIT_V) {
    faultReason = 4;
  } else if (temp > TEMP_HIGH_LIMIT || temp < TEMP_LOW_LIMIT) {
    faultReason = 5;
  }

  if (configWindowOpen) {
    // Non-latching while tuning: MOSFET/fault state track the live
    // comparison against whatever limits are currently set, so widening
    // a limit clears the fault immediately instead of requiring a reset.
    faultLatched = (faultReason != 0);
  } else {
    // Normal latching behavior once tuning is over: a fault, once
    // tripped, stays tripped until the board is physically reset.
    if (faultReason != 0)
      faultLatched = true;
  }

  mosfetOn = faultLatched;
  digitalWrite(MOSFET_PIN, mosfetOn ? HIGH : LOW);

  if (faultLatched) {
    if (millis() - lastBuzz >= BUZZ_PERIOD_MS) {
      lastBuzz = millis();
      buzzState = !buzzState;
      digitalWrite(BUZZER_PIN, buzzState ? HIGH : LOW);
    }
  } else {
    digitalWrite(BUZZER_PIN, LOW);
  }
}

void applySerialCommand(String line) {
  line.trim();
  if (line.length() == 0) return;

  bool windowOpen = (millis() - bootTime <= CONFIG_WINDOW_MS);
  if (!windowOpen) {
    Serial1.println("[WARN] Configuration window closed (60s elapsed). Reset the BMS to reconfigure.");
    return;
  }

  if (line == "1") {
    inConfigMode = true;
    Serial1.println("[SYS] Entered Configuration Mode. Telemetry Paused.");
    return;
  }
  if (line == "0") {
    inConfigMode = false;
    Serial1.println("[SYS] Exited Configuration Mode. Resuming Telemetry.");
    return;
  }

  int sep = line.indexOf(':');
  if (sep == -1) {
    Serial1.println("[ERR] Unrecognized command");
    return;
  }

  String key = line.substring(0, sep);
  float val = line.substring(sep + 1).toFloat();

  if (key == "SET_V") {
    BUS_VOLTAGE_LIMIT = val;
    Serial1.print("[CFG] BUS_VOLTAGE_LIMIT=");
    Serial1.println(BUS_VOLTAGE_LIMIT, 3);
  } else if (key == "SET_IH") {
    OCP_LIMIT_A = val;
    ina226Write(REG_ALERT, computeAlertReg());
    Serial1.print("[CFG] OCP_LIMIT_A=");
    Serial1.println(OCP_LIMIT_A, 3);
  } else if (key == "SET_IL") {
    CURRENT_LOWER_LIMIT_A = val;
    Serial1.print("[CFG] CURRENT_LOWER_LIMIT_A=");
    Serial1.println(CURRENT_LOWER_LIMIT_A, 3);
  } else if (key == "SET_TL") {
    TEMP_LOW_LIMIT = val;
    Serial1.print("[CFG] TEMP_LOW_LIMIT=");
    Serial1.println(TEMP_LOW_LIMIT, 2);
  } else if (key == "SET_TH") {
    TEMP_HIGH_LIMIT = val;
    Serial1.print("[CFG] TEMP_HIGH_LIMIT=");
    Serial1.println(TEMP_HIGH_LIMIT, 2);
  } else if (key == "SET_H2") {
    H2_LIMIT_V = val;
    Serial1.print("[CFG] H2_LIMIT_V=");
    Serial1.println(H2_LIMIT_V, 2);
  } else if (key == "SET_RATE") {
    if (val > 0) {
      CSV_PERIOD_MS = (uint32_t)val;
      Serial1.print("[CFG] CSV_PERIOD_MS=");
      Serial1.println(CSV_PERIOD_MS);
    } else {
      Serial1.println("[ERR] Invalid rate");
    }
  } else {
    Serial1.println("[ERR] Unknown key");
  }
}

void handleIncomingSerial() {
  while (Serial1.available() > 0) {
    char c = Serial1.read();

    if (c == '\n') {
      rxLineBuffer.trim();
      // Only accept lines that actually look like one of our commands.
      // Anything else (stray echoed debug text, noise, etc.) is dropped
      // silently instead of being fed to the parser.
      if (rxLineBuffer == "0" || rxLineBuffer == "1" || rxLineBuffer.startsWith("SET_")) {
        applySerialCommand(rxLineBuffer);
      }
      rxLineBuffer = "";
    } else if (c == '\r') {
      // ignore
    } else if (isPrintable(c)) {
      rxLineBuffer += c;
      if (rxLineBuffer.length() > 40) rxLineBuffer = "";  // overflow guard
    }
    // non-printable bytes (noise/corruption) are dropped, not appended
  }
}

void setup() {
  pinMode(ALERT_PIN, INPUT_PULLUP);
  pinMode(BUZZER_PIN, OUTPUT);
  pinMode(MOSFET_PIN, OUTPUT);
  digitalWrite(BUZZER_PIN, LOW);
  digitalWrite(MOSFET_PIN, LOW);

  analogReadResolution(12);
  ina226Init();

  if (ENABLE_UART_TELEMETRY) {
    Serial1.begin(115200);
    Serial1.println("DATA,bus_V,current_A,power_W,temp_C,h2_V,mosfet,faultReason");
    bootTime = millis();
  }
}

void loop() {
  float busV = readBusVoltage();
  float cur = readCurrent();
  float pw = readPower();
  float temp = readTemperature();
  float h2 = readH2();

  // Safety checks always execute regardless of UART state
  checkFaults(busV, cur, temp, h2);

  if (ENABLE_UART_TELEMETRY) {
    uint32_t currentMillis = millis();

    // 1. RX Listening Logic — always active so settings can be pushed
    //    any time from the PC app, not just in the boot window.
    handleIncomingSerial();

    // 2. CSV Telemetry Output (Only transmits when NOT in config mode)
    if (!inConfigMode && (currentMillis - lastCsv >= CSV_PERIOD_MS)) {
      lastCsv = currentMillis;

      Serial1.print("DATA,");
      Serial1.print(busV, 3);
      Serial1.print(",");
      Serial1.print(cur, 3);
      Serial1.print(",");
      Serial1.print(pw, 3);
      Serial1.print(",");
      Serial1.print(temp, 2);
      Serial1.print(",");
      Serial1.print(h2, 2);
      Serial1.print(",");
      Serial1.print(mosfetOn ? 1 : 0);
      Serial1.print(",");
      Serial1.println(faultReason);
    }
  }
}

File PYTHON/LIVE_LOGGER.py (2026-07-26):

import sys
import serial
import csv
from datetime import datetime
from pathlib import Path

from PyQt5 import QtWidgets, QtCore
import pyqtgraph as pg

# ==========================
# Configuration
# ==========================
PORT = "/dev/ttyUSB0"          # Linux
# PORT = "COM5"                 # Windows
BAUDRATE = 115200
SAVE_FOLDER = "DATA_LOGS"

UPDATE_INTERVAL_MS = 1000         # how often (ms) we poll serial + redraw plots
RECONNECT_INTERVAL_MS = 2000    # how often we retry opening the port when disconnected
MAX_SAMPLES = 50000             # safety cap so a multi-hour run doesn't grow forever

BATTERY_WEIGHT_KG = 1.0         # <-- EDIT ME: physical weight of the battery under test (kg)

# Must match the STM32 fault codes exactly (see checkFaults() in the firmware)
FAULT_MESSAGES = {
    0: "No Fault",
    1: "INA226 Alert",
    2: "Bus Voltage",
    3: "Over Current",
    4: "Hydrogen",
    5: "Temperature",
    6: "Under Current",
}

# ==========================
# CSV setup
# ==========================
Path(SAVE_FOLDER).mkdir(exist_ok=True)

filename = datetime.now().strftime("DATA_%d_%m_%Y-%H_%M_%S.csv")
filepath = Path(SAVE_FOLDER) / filename

counter = 1
while filepath.exists():
    filename = datetime.now().strftime(f"DATA_%d_%m_%Y-%H_%M_%S_{counter}.csv")
    filepath = Path(SAVE_FOLDER) / filename
    counter += 1

print(f"Saving to: {filepath}")

csv_file = open(filepath, "w", newline="")
writer = csv.writer(csv_file)
writer.writerow([
    "PC Time",
    "Voltage (V)",
    "Current (A)",
    "Power (W)",
    "Temperature (°C)",
    "Hydrogen (V)",
    "MOSFET",
    "Fault Reason",
    "Fault Text",
    "Energy (Wh)",
    "Capacity (Ah)",
    "Energy Density (Wh/kg)",
])
csv_file.flush()


class _CardFrame(QtWidgets.QFrame):
    """
    A QFrame that can host a small overlay button pinned to its top-right
    corner (fixed padding from the top and right edges). The button floats
    over the card's normal contents and is repositioned automatically
    whenever the card is resized, so it stays put as the layout stretches.
    """

    def __init__(self, *args, **kwargs):
        super().__init__(*args, **kwargs)
        self._overlay_btn = None
        self._overlay_margin = 16

    def set_overlay_button(self, btn, margin=16):
        self._overlay_btn = btn
        self._overlay_margin = margin
        btn.setParent(self)
        btn.raise_()
        self._position_overlay()

    def resizeEvent(self, event):
        super().resizeEvent(event)
        self._position_overlay()

    def _position_overlay(self):
        if self._overlay_btn is None:
            return
        m = self._overlay_margin
        x = self.width() - self._overlay_btn.width() - m
        y = m
        self._overlay_btn.move(x, y)


class LiveGraphWindow(QtWidgets.QMainWindow):
    """
    Main window. A fast QTimer polls the serial port and redraws the plots;
    a slower QTimer retries the connection whenever the port is closed or
    the cable gets unplugged mid-run. Every valid packet is logged to CSV
    exactly like before, plus the derived energy/capacity/energy-density
    figures.
    """

    def __init__(self):
        super().__init__()
        self.setWindowTitle("BMS LIVE LOGGER")
        self.resize(1300, 1500)

        # ---- serial connection state ----
        self.ser = None
        self.connected = False

        # ---- session state (for energy / capacity integration) ----
        self.start_time = None
        self.prev_time = None
        self.prev_power = 0.0
        self.energy_wh = 0.0

        # ---- data buffers -- x-axis is elapsed minutes since first sample ----
        self.t = []
        self.voltage = []
        self.current = []
        self.power = []
        self.temperature = []
        self.hydrogen = []
        self.capacity = []

        # ---- build UI ----
        # Everything lives inside a scroll area so that on smaller/laptop
        # screens, plots that don't fit vertically can be scrolled to
        # instead of being clipped off-screen.
        scroll_area = QtWidgets.QScrollArea()
        scroll_area.setWidgetResizable(True)
        self.setCentralWidget(scroll_area)

        content = QtWidgets.QWidget()
        scroll_area.setWidget(content)
        main_layout = QtWidgets.QVBoxLayout(content)

        self._build_status_bars(main_layout)

        self._build_time_series_plots(main_layout)
        self._build_correlation_plots(main_layout)

        # ---- slide-out settings panel (defaults must mirror the firmware) ----
        self.current_settings = {
            "voltage_cutoff": 0.8,
            "current_upper": 16.0,
            "current_lower": 0.0,
            "temp_lower": 25.0,
            "temp_upper": 45.0,
            "hydrogen_limit": 4.0,
            "data_rate": 1700,
        }
        self.bms_boot_time = None       # set when serial connects; used for the 60s config window
        self.CONFIG_WINDOW_SECONDS = 60  # must match CONFIG_WINDOW_MS in the firmware
        self._build_settings_panel()
        self._position_settings_panel()

        # ---- timers ----
        self.data_timer = QtCore.QTimer()
        self.data_timer.timeout.connect(self.read_serial_and_update)
        self.data_timer.start(UPDATE_INTERVAL_MS)

        self.reconnect_timer = QtCore.QTimer()
        self.reconnect_timer.timeout.connect(self.try_connect)
        self.reconnect_timer.start(RECONNECT_INTERVAL_MS)

        self.try_connect()  # attempt once immediately at startup

    # ------------------------------------------------------------------
    # UI builders
    # ------------------------------------------------------------------
    def _build_status_bars(self, main_layout):
        self.value_labels = {}

        # Row 1 - live sensor readings (6 cards, all equal width/height/gap)
        readings_bar = QtWidgets.QHBoxLayout()
        readings_bar.setSpacing(10)
        metrics = [
            ("voltage", "VOLTAGE", "V"),
            ("current", "CURRENT", "A"),
            ("power", "POWER", "W"),
            ("temperature", "TEMPERATURE", "°C"),
            ("hydrogen", "HYDROGEN", "V"),
        ]

        for key, title, unit in metrics:
            card, value_label = self._make_value_card(title, unit)
            self.value_labels[key] = value_label
            readings_bar.addWidget(card, 1)  # stretch=1 -> every card gets an equal share of the width

        # Energy Density card (contains the menu button) -- same stretch as the rest
        card, value_label = self._make_value_card(
            "ENERGY DENSITY",
            "Wh/kg",
            menu_button=True
        )
        self.value_labels["energy_density"] = value_label
        readings_bar.addWidget(card, 1)
        main_layout.addLayout(readings_bar)
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

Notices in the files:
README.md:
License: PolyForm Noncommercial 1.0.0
